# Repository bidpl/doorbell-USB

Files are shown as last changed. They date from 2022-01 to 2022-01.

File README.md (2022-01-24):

# Wake On Doorbell (WoD) USB Dongle

A USB stick that sends a spacebar press when the doorbell is pressed. Used to wake a door surveillence monitor when someone rings the doorbell.

Takes a AC signal through the barrel jack (doorbell wires). The onboard microcontroller acts as a USB keyboard while monitoring the signal for a drop in the average voltage (doorbell pressed). When it detects the decrease in voltage, it sends a spacebar keypress to wake the computer.

Assembled WoD USB Dongle:
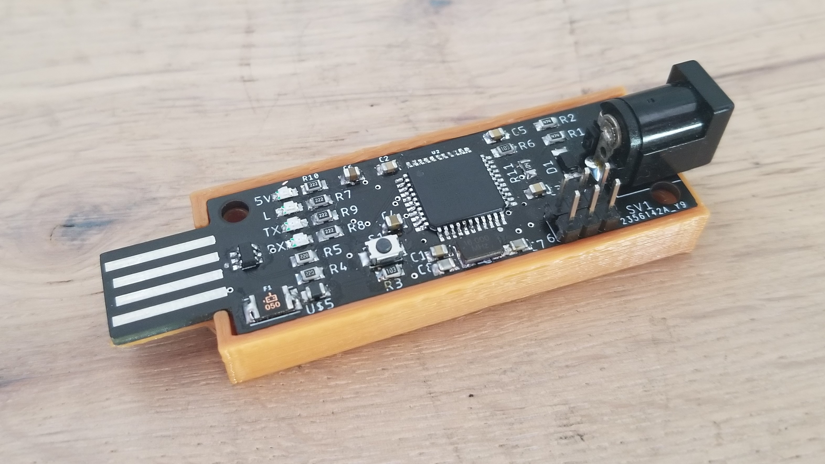
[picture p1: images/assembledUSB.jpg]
Assembled WoD USB Dongle


WoD USB Dongle installed on a PC
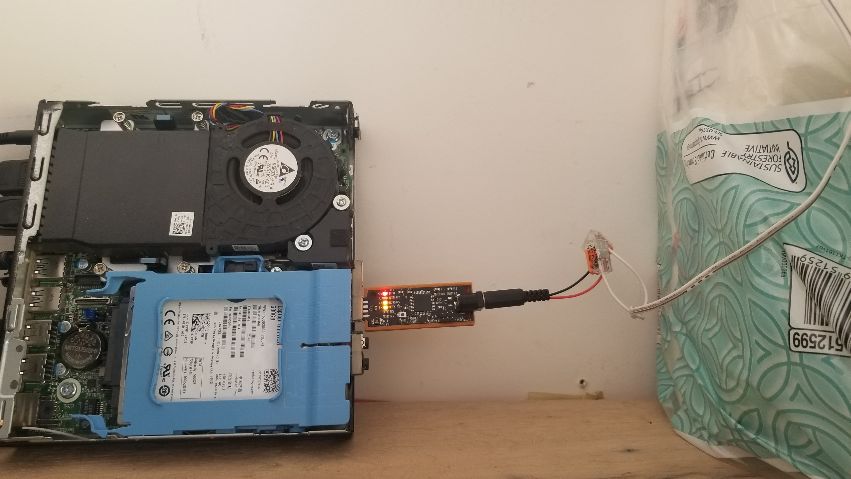
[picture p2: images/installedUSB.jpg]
Installed WoD USB Dongle


## The stick itself

v1.0
Yay it works!
No errors found during testing and use.

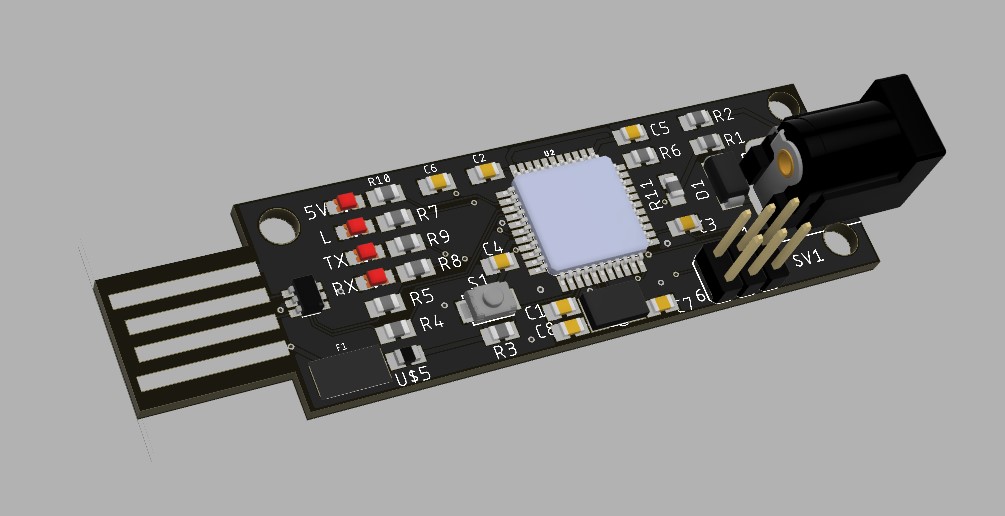
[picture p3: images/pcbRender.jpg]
Render of PCB


## Case

A press fit case for the PCB. It has some screw holes, but the press fit is enough to hold it in. The tab for the USB connector is sized to increase the thickness of the connector to ~2.2mm.

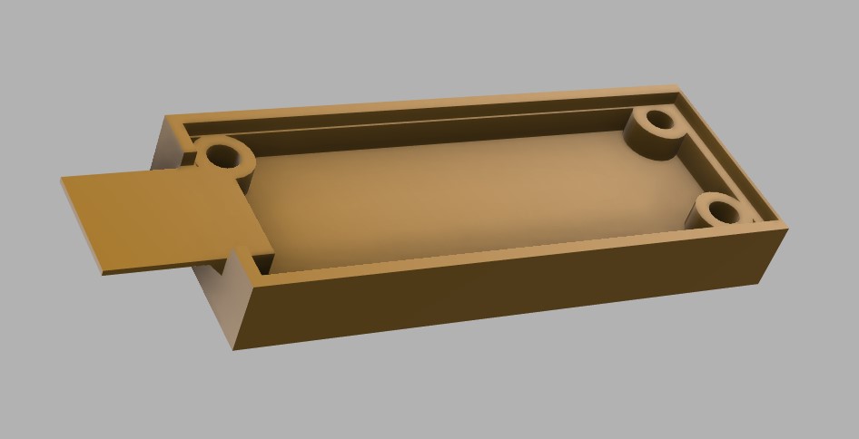
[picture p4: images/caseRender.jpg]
Render of Case


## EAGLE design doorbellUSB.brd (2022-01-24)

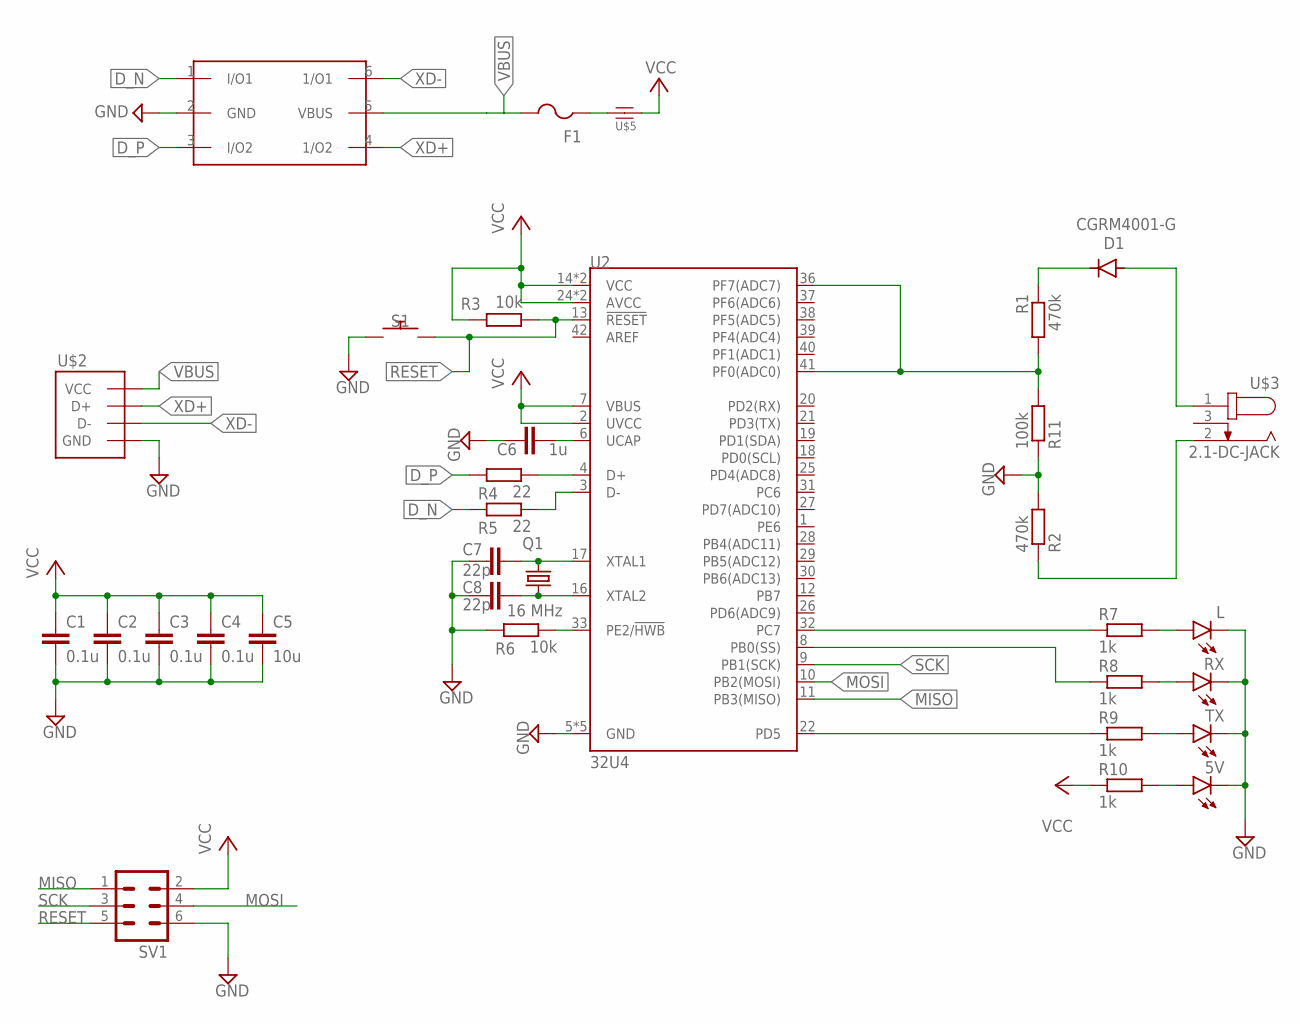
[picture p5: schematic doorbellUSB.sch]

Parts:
5V: LEDCHIP-LED0805; CHIP-LED0805
C1, C2, C3, C4: 0.1u; C0805
C5: 10u; C0805
C6: 1u; C0805
C7, C8: 22p; C0805
D1: CGRM4001-G; SOD-123_MINI-SMA
F1: PTCFUSE-1812; 1812
L: LEDCHIP-LED0805; CHIP-LED0805
Q1: 16 MHz; 5.0X3.2_2
R1, R2: 470k; R0805
R3, R6: 10k; R0805
R4, R5: 22; R0805
R7, R8, R9, R10: 1k; R0805
R11: 100k; R0805
RX: LEDCHIP-LED0805; CHIP-LED0805
S1: 3X4MM-PUHSBUTTON; 3X4MM-PUSHBUTTON
SV1: MA03-2
TX: LEDCHIP-LED0805; CHIP-LED0805
U2: 32U4; TQFP44
U$1: USBLC-2; SOT23-6L
U$2: PCB-USB-A; USB-A-ONBOARD
U$3: 2.1-DC-JACK; 2.1X5.5MM_JACK
U$5: FERRITE-BEAD; R0805

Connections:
DATA_N: R5.2, U2.3 (D-)
DATA_P: R4.2, U2.4 (D+)
D_N: R5.1, U$1.1 (I/O1)
D_P: R4.1, U$1.3 (I/O2)
GND: 5V.C, C1.2, C2.2, C3.2, C4.2, C5.2, C6.1, C7.2, C8.2, L.C, R2.2, R6.1, R11.1, RX.C, S1.P$1, SV1.6, TX.C, U2.5 (GND), U2.15 (GND), U2.23 (GND), U2.35 (GND), U2.43 (GND), U$1.2 (GND), U$2.GND
MISO: SV1.1, U2.11 (PB3(MISO))
MOSI: SV1.4, U2.10 (PB2(MOSI))
unnamed: R2.1, U$3.2
unnamed: D1.A, U$3.1
unnamed: D1.C, R1.1
unnamed: R1.2, R11.2, U2.36 (PF7(ADC7)), U2.41 (PF0(ADC0))
unnamed: R8.1, U2.8 (PB0(SS))
unnamed: C6.2, U2.6 (UCAP)
unnamed: R9.1, U2.22 (PD5)
unnamed: R7.1, U2.32 (PC7)
unnamed: L.A, R7.2
unnamed: R9.2, TX.A
unnamed: R6.2, U2.33 (PE2/!HWB)
unnamed: F1.1, U$5.2
unnamed: R8.2, RX.A
unnamed: 5V.A, R10.2
RESET: R3.2, S1.P$2, SV1.5, U2.13 (!RESET)
SCK: SV1.3, U2.9 (PB1(SCK))
VBUS: F1.2, U$1.5 (VBUS), U$2.VCC
VCC: C1.1, C2.1, C3.1, C4.1, C5.1, R3.1, R10.1, SV1.2, U2.2 (UVCC), U2.7 (VBUS), U2.14 (VCC), U2.24 (AVCC), U2.34 (VCC), U2.44 (AVCC), U$5.1
XD+: U$1.4 (1/O2), U$2.D+
XD-: U$1.6 (1/O1), U$2.D-
XTAL_1: C8.1, Q1.1, U2.16 (XTAL2)
XTAL_2: C7.1, Q1.2, U2.17 (XTAL1)

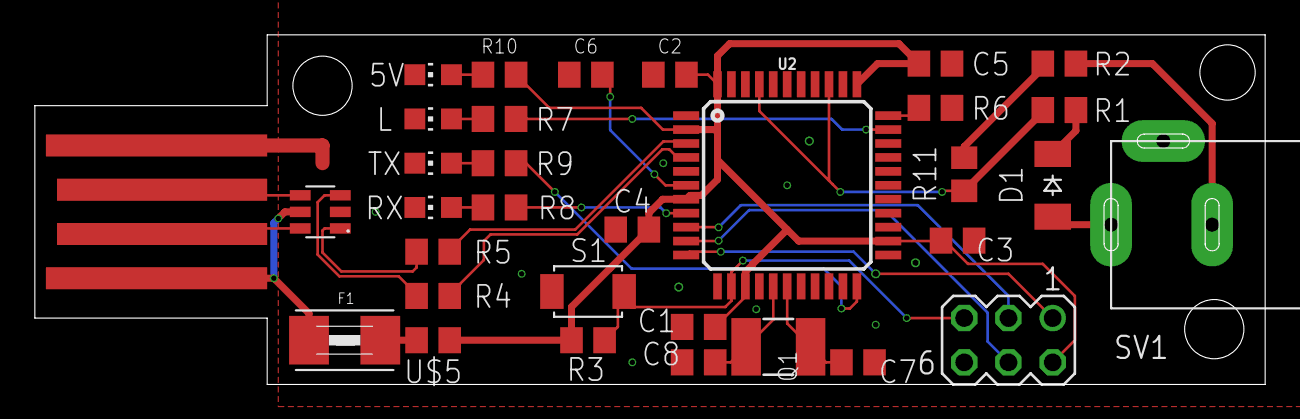
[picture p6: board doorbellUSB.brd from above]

Board: 2 copper layers, 70.6 x 20.1 mm, 33 parts (0 on the bottom side), 29 nets.

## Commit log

2022-01-24 Turned project into git repo. Added images and README.md
    [doorbellUSB.brd, doorbellUSB.sch]
2022-01-24 Cropped assembledUSB.jpg, edited README.md (reordered images and captions.

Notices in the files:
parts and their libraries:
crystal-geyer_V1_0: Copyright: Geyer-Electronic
